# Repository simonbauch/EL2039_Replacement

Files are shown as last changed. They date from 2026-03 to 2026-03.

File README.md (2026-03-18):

# EL2039_Replacement
A replacement PCB for the commonly failing EL2039 on the AC boards of 3458As. 

This is accomplished using a THS4631DGNR from TI as the opamp in the AC amp on the A2 PCB. (like newer 3458As do) To stay in the proper operating voltage range a 3V Zener dropper is used on the -17V rail.

This replacement board passes Selftest and ACAL AC, more tests haven't been done yet. It fits mechananically below the shield.

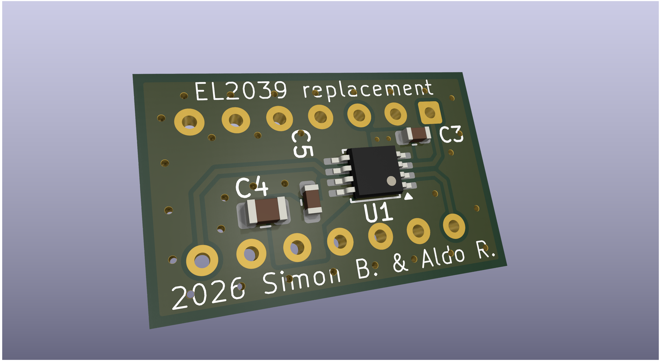
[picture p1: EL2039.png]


Here in action:

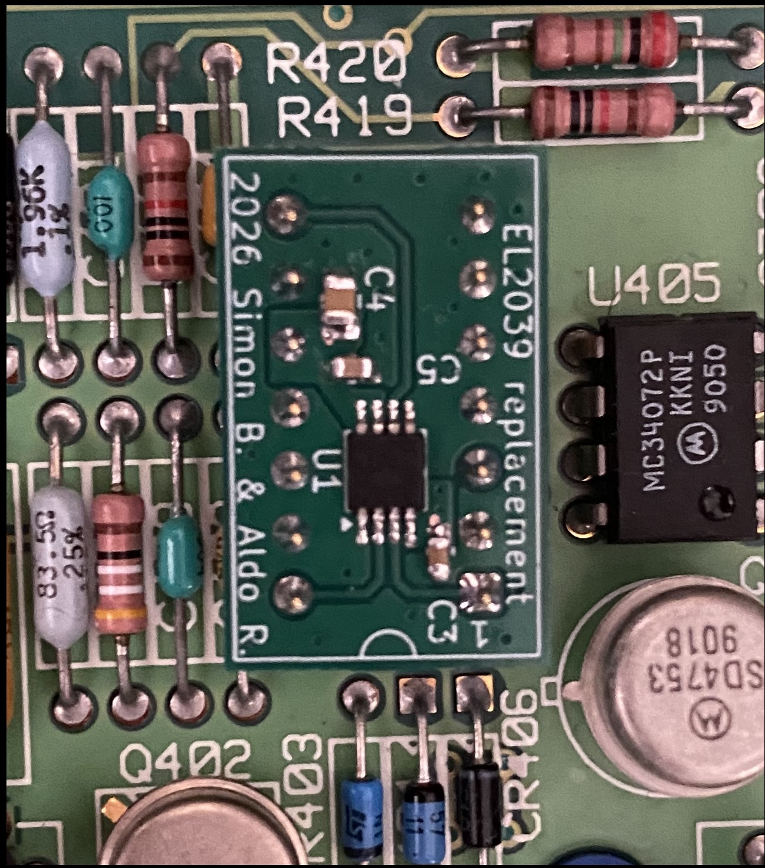
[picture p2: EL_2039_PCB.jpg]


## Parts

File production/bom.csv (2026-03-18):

Designator | Footprint | Quantity | Value | LCSC Part #
C1 | CP_EIA-6032-15_Kemet-U | 1 | 22u
C2, C4 | 0805 | 2 | 1u
C3, C5 | 0603 | 2 | 100n
D1 | D_SOD-123 | 1 | MMSZ4683T1G
J1 | DIP-14_W7.62mm | 1 | 2x 7 Pin Header
U1 | MSOP-8-1EP_3x3mm_P0.65mm_EP1.5x1.8mm | 1 | THS4631DGNR

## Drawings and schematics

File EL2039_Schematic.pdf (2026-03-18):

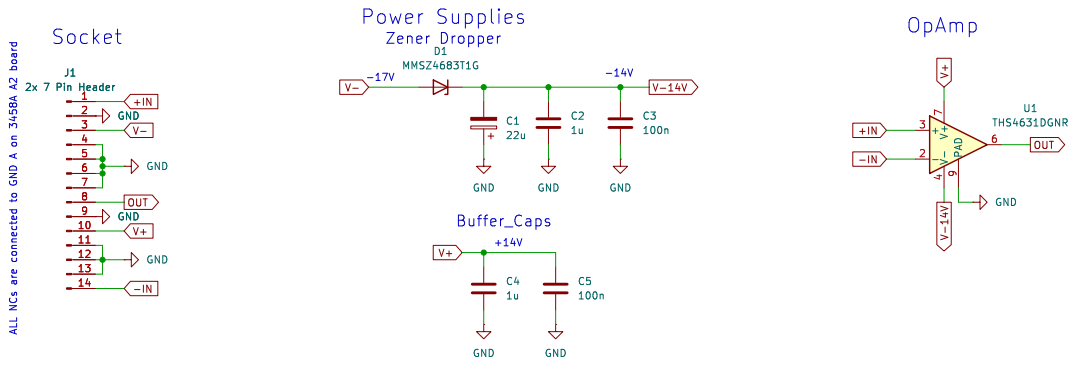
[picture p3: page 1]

Id: 1/1 Title: File: EL2039.kicad_sch Sheet: /

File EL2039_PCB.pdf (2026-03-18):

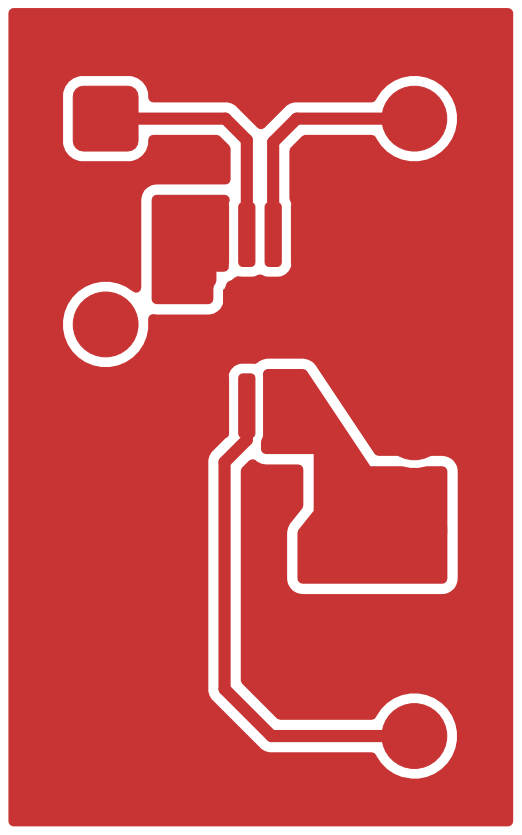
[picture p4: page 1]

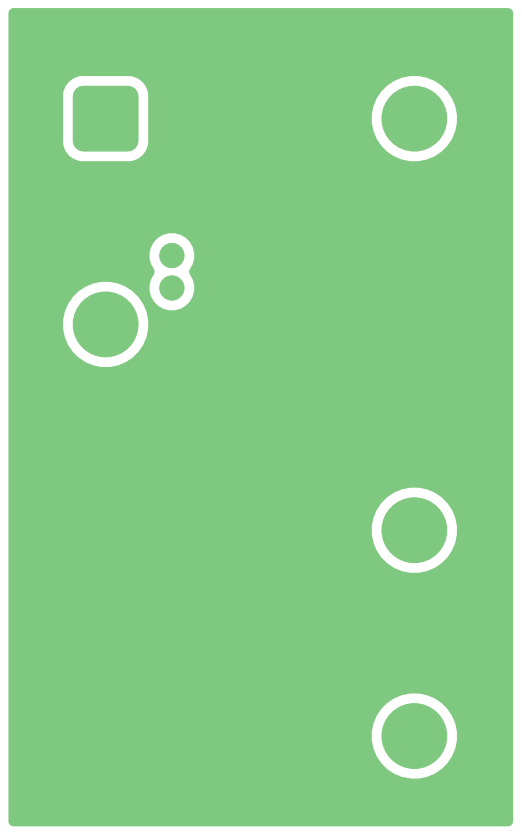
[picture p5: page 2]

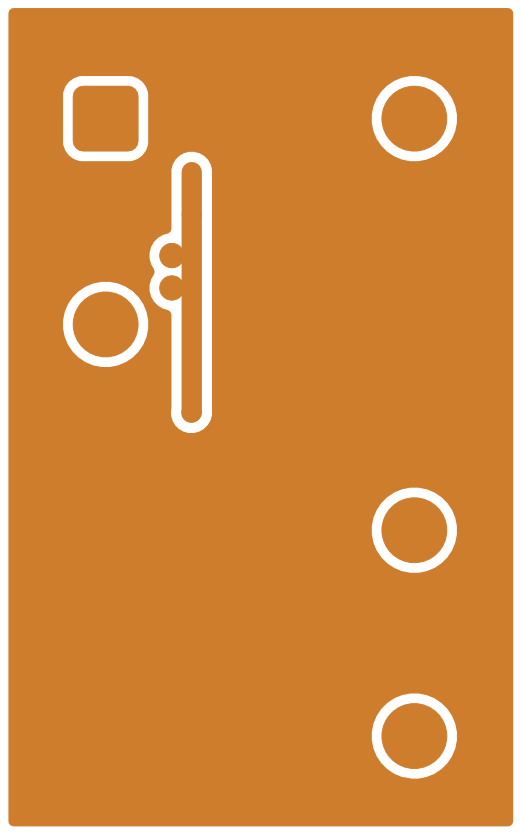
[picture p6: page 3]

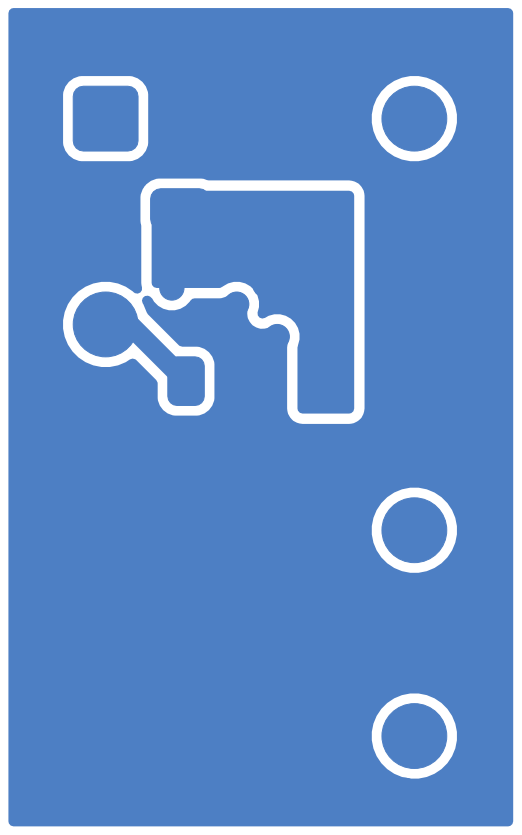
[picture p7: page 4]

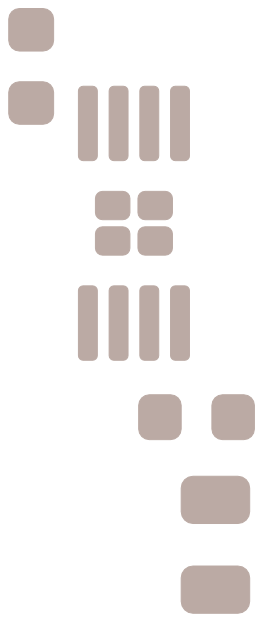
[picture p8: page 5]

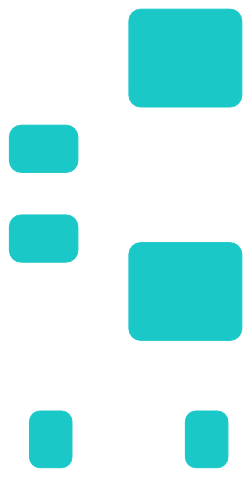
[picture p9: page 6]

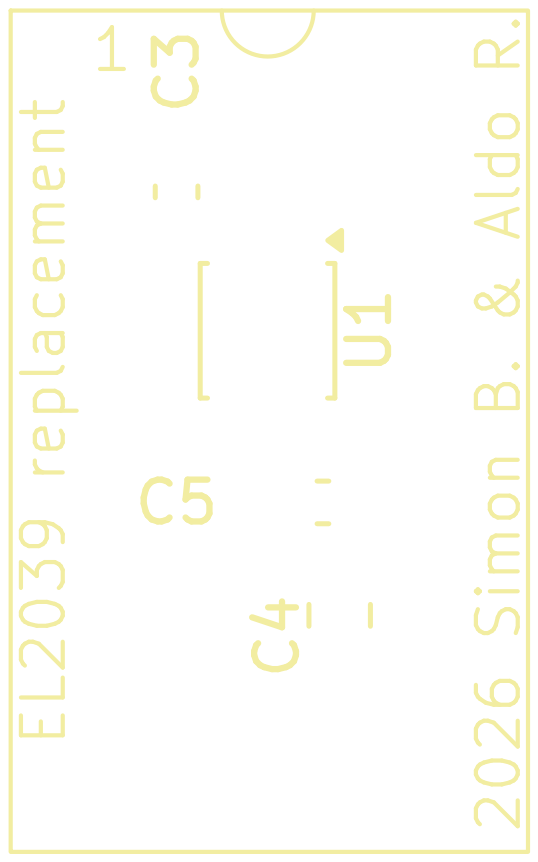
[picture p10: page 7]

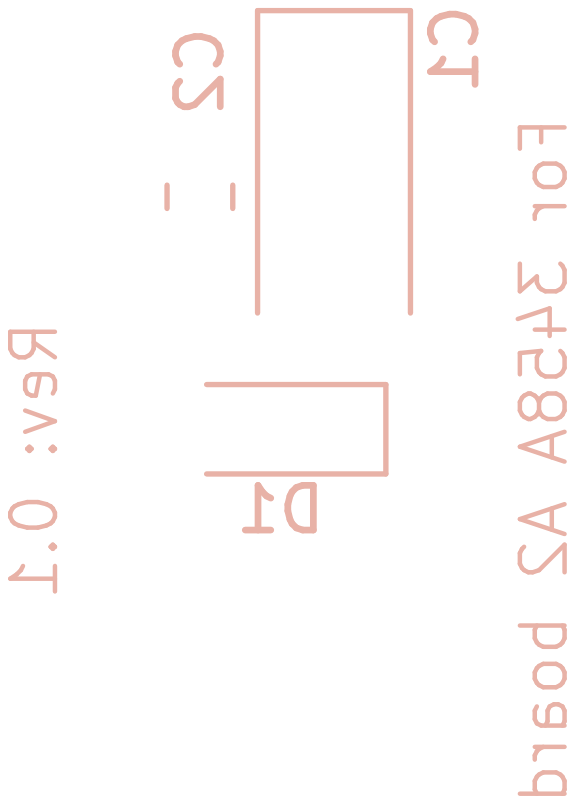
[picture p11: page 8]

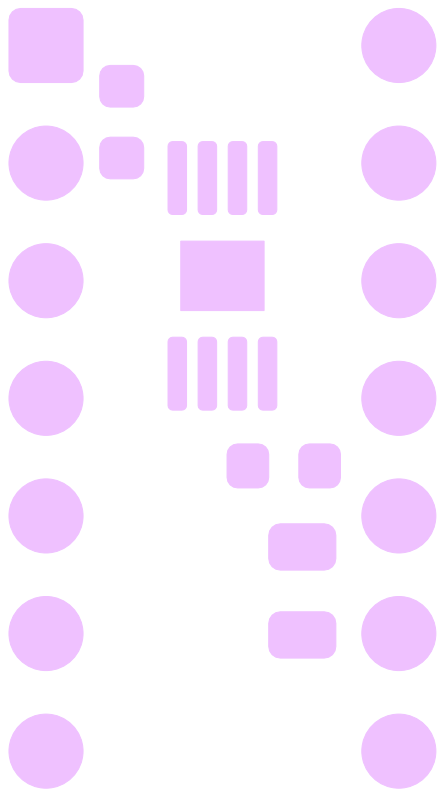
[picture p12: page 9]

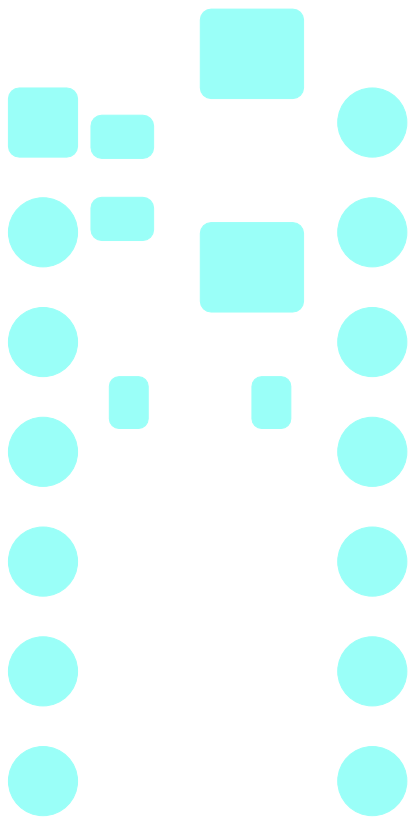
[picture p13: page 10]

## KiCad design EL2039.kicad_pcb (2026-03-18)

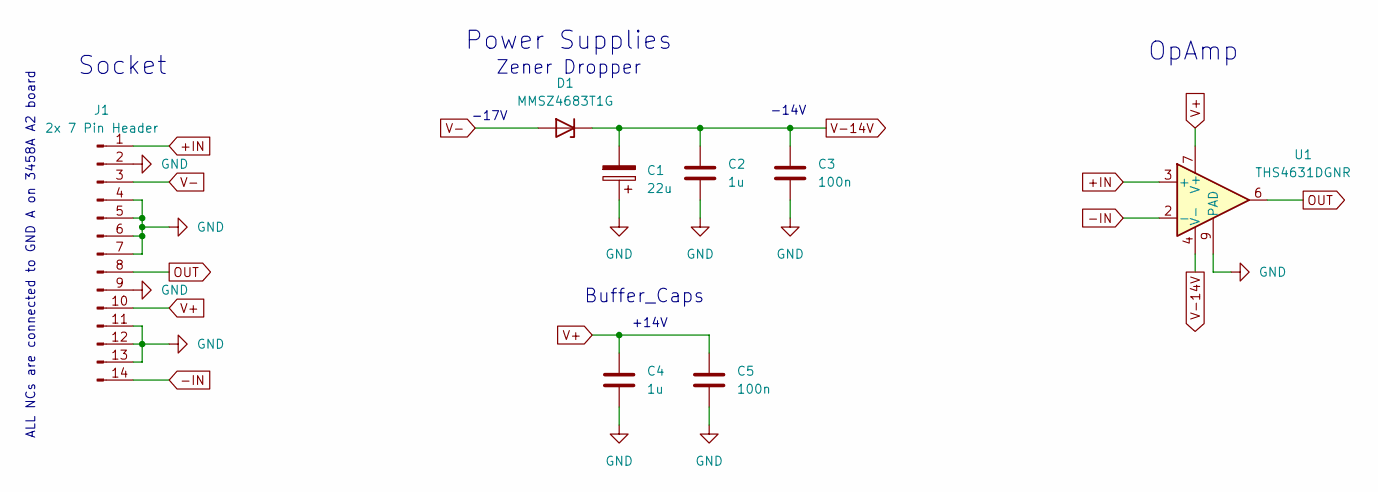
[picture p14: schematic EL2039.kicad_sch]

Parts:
C1: 22u; CP_EIA-6032-15_Kemet-U
C2, C4: 1u; C_0805_2012Metric
C3, C5: 100n; C_0603_1608Metric
D1: MMSZ4683T1G; D_SOD-123
J1: 2x 7 Pin Header; DIP-14_W7.62mm
U1: THS4631DGNR; MSOP-8-1EP_3x3mm_P0.65mm_EP1.5x1.8mm

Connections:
+IN: J1.1, U1.3 (+)
-IN: J1.14, U1.2 (-)
GND: C1.1, C2.2, C3.2, C4.2, C5.2, J1.2, J1.4, J1.5, J1.6, J1.7, J1.9, J1.11, J1.12, J1.13, U1.1 (NC), U1.5 (NC), U1.9 (PAD)
OUT: J1.8, U1.6
V+: C4.1, C5.1, J1.10, U1.7 (V+), U1.8 (NC)
V-: D1.2 (A), J1.3
V-14V: C1.2, C2.1, C3.1, D1.1 (K), U1.4 (V-)

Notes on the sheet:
-14V
Buffer_Caps
OpAmp
+14V
-17V
Socket
Power Supplies
ALL NCs are connected to GND A on 3458A A2 board
Zener Dropper

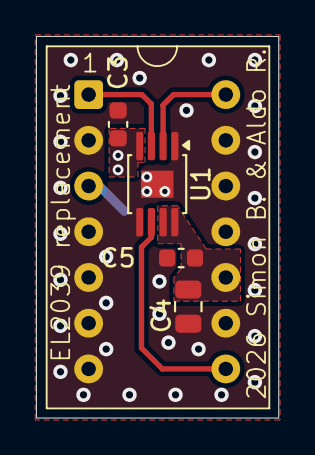
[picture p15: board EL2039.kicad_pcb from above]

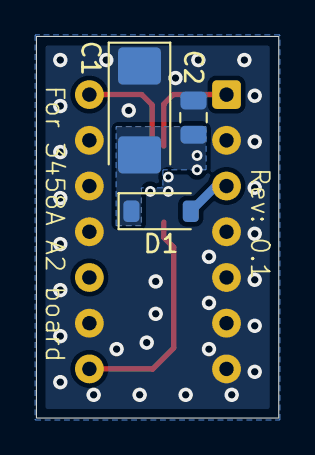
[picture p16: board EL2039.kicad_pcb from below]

Board: 4 copper layers, 13.5 x 21.2 mm, 8 parts (3 on the bottom side), 7 nets.
